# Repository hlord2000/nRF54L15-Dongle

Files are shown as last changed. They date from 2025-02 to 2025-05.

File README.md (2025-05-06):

# Hardware Design with the nRF54L15 is Easy: Making an nRF54L15 Dongle in KiCad

TODO: add flash part, explain firmware bringup on board, get some made 

Everyone knows the nRF52840 dongle! It's an excellent way to prototype with BLE, USB, or Nordic's proprietary protocols ("Enhanced ShockBurst", "Gazelle"). As solid as the dongle is, it's time to add new features and creature comforts to the foundation it gave us. 

First, a short comparison of the nRF54L15 and the nRF52840. Why make the leap to the nRF54L15?
- The nRF54L15 is based on a modern 22nm process, showing a 2x performance increase and half of the power consumption of the nRF52840.
- The nRF54L15 has expanded non-volatile memory as compared to the nRF52840 with 1.5MB onboard (+512KB).
- The nRF54L15 has a peripheral RISC-V core (cool!) which has a lot of interesting uses. It can be used as another core running Zephyr RTOS or as a software defined peripheral with libraries we provide!
- A new 4mbps PHY is available (this supports proprietary protocols only at time of writing).
- New security features are available in the nRF54L15 including a key management unit (KMU), TrustZone, side channel attack detection, and hardware tamper detectors.

How do you perfect perfection? What does an nRF54L15 dongle look like? Any tradeoffs? Here are some things to consider:
- The nRF54L15 does not have a USB interface. We need some sort of chip between the L15 and host device. I propose that we use an nRF52833 to act as a UART bridge and add some extra functionality...
- As seen in the Thingy91 X, it is possible to create a CMSIS-DAP debugger with Zephyr! I'll connect the SWDCLK/SWDIO/RESET pins from the nRF54L15 to the nRF52833.
- Let's add some quality of life items: a STEMMA-QT/Qwiic connector and through holes with castellations.
- It is time for USB-C! We will use a USB-C plug so that it is a true dongle.
- For DFU purposes, we will include a small external flash part connected to the nRF54L15.
- We are not typically power limited with a dongle and do not need a connection to a battery. For more information on power consumption with the nRF54L15, check out the Online Power Profiler here: ##INCLUDE LINK##

We've defined our system, let's make a diagram:

<p align="center">
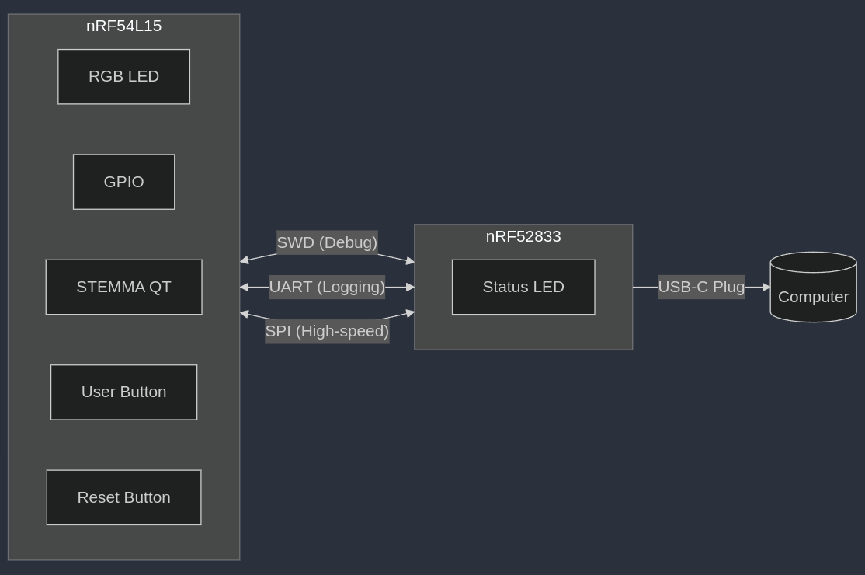
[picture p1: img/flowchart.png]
  
</p>

I personally use KiCad for all hardware design I do. It's quite close to being an outright Altium replacement and the price (free) is hard to pass up. Check out my KiCad library for Nordic parts https://github.com/hlord2000/nordic-lib-kicad if you are also interested!

The nRF52833 can be powered directly from USB, but the nRF54L15 will need a 5V->3.3V regulator. Let's combine this with the USB-C plug and protection IC. 

<p align="center">
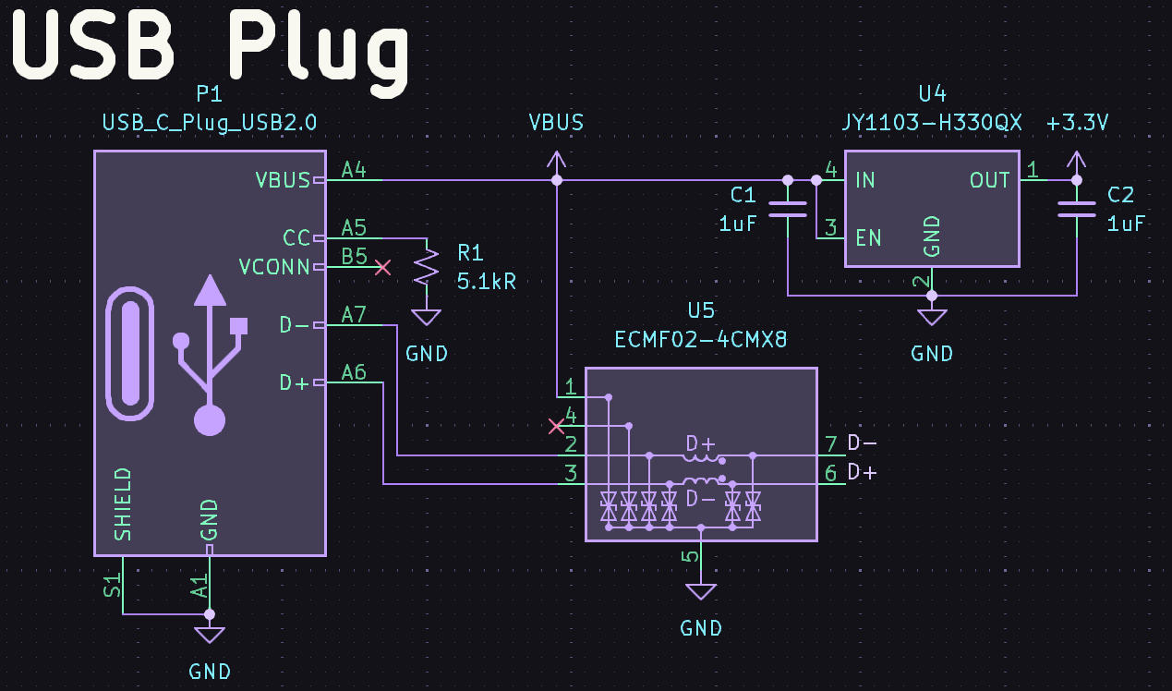
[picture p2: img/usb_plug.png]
  
</p>

Note the use of a 5.1k pull down resistor on the CC pin of the plug. This tells the upstream device, typically a computer, that this is a downstream device that can sink up to 500mA. If you were to need more power, consider using a dedicated USB power delivery (PD) PHY.

Let's move on to the nRF52833 debugger.

<p align="center">
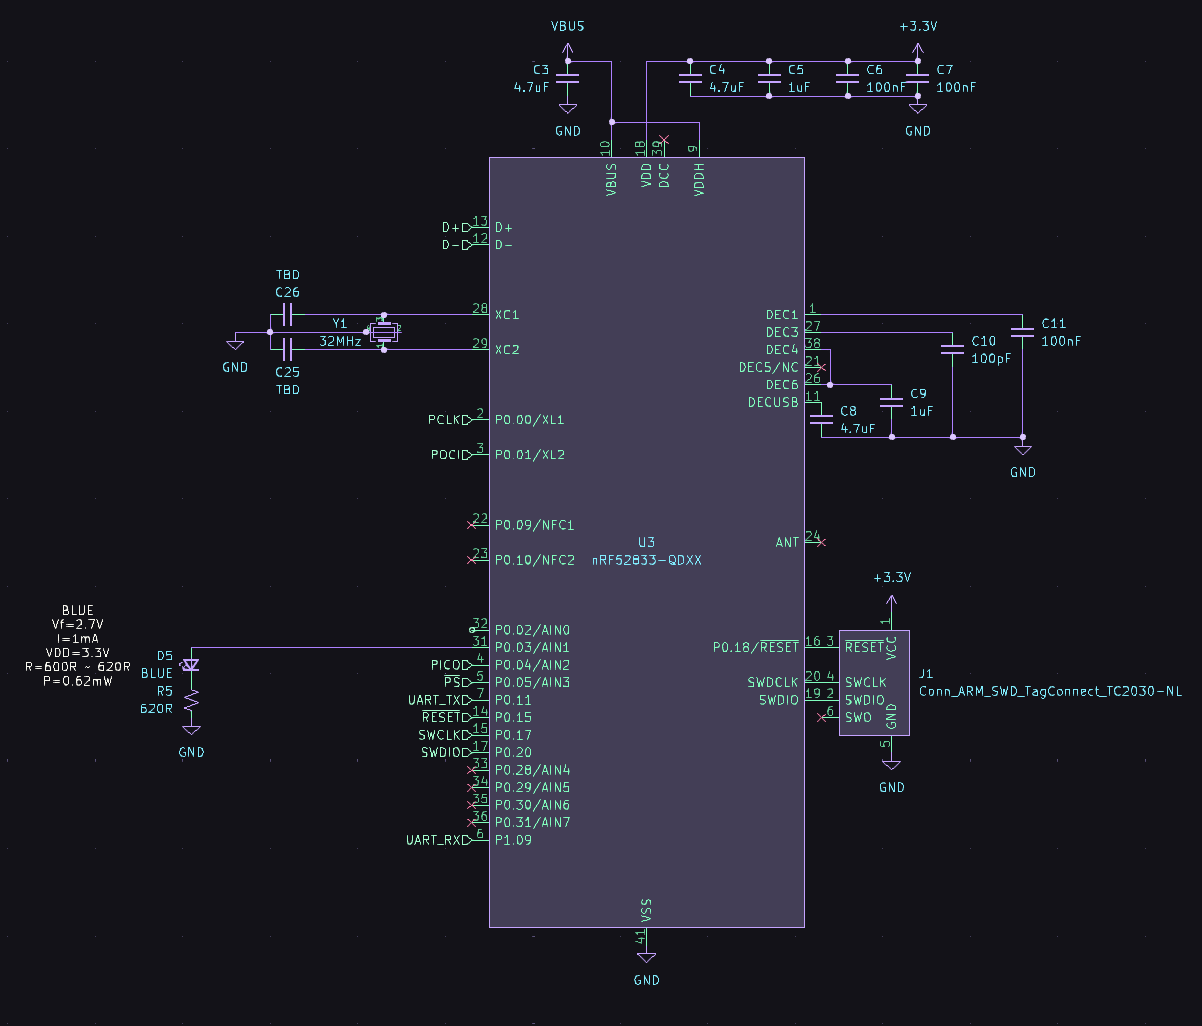
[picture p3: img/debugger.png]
  
</p>

There is no need for an external 32.768KHz crystal oscillator since this design is not power constrained, so we'll use the internal RC oscillator. Any pins can be used for the peripherals on the nRF52833 and the SWD pins are bit-banged anyway, so I have connected them to the most convenient pins for routing to the nRF54L15. One small exception is the pins required to use the 32MHz high-speed SPI interface on the nRF52833 (which requires specific pins for full speed operation).

The nRF52833 debugger can itself be programmed through a Tag Connect TC2030 footprint. This saves a line on the BOM and seems to be quite common in industry. Tag Connect sells a cable that can connect to the debug out port on any Nordic devkit. The onboard debugger will also feature MCUBoot USB DFU if it becomes necessary to update firmware.

Now for the star of the show! I have added the nRF54L15 in QFN package, following the reference design available here (## INCLUDE LINK ##) to ensure correct passive component values. 

<p align="center">
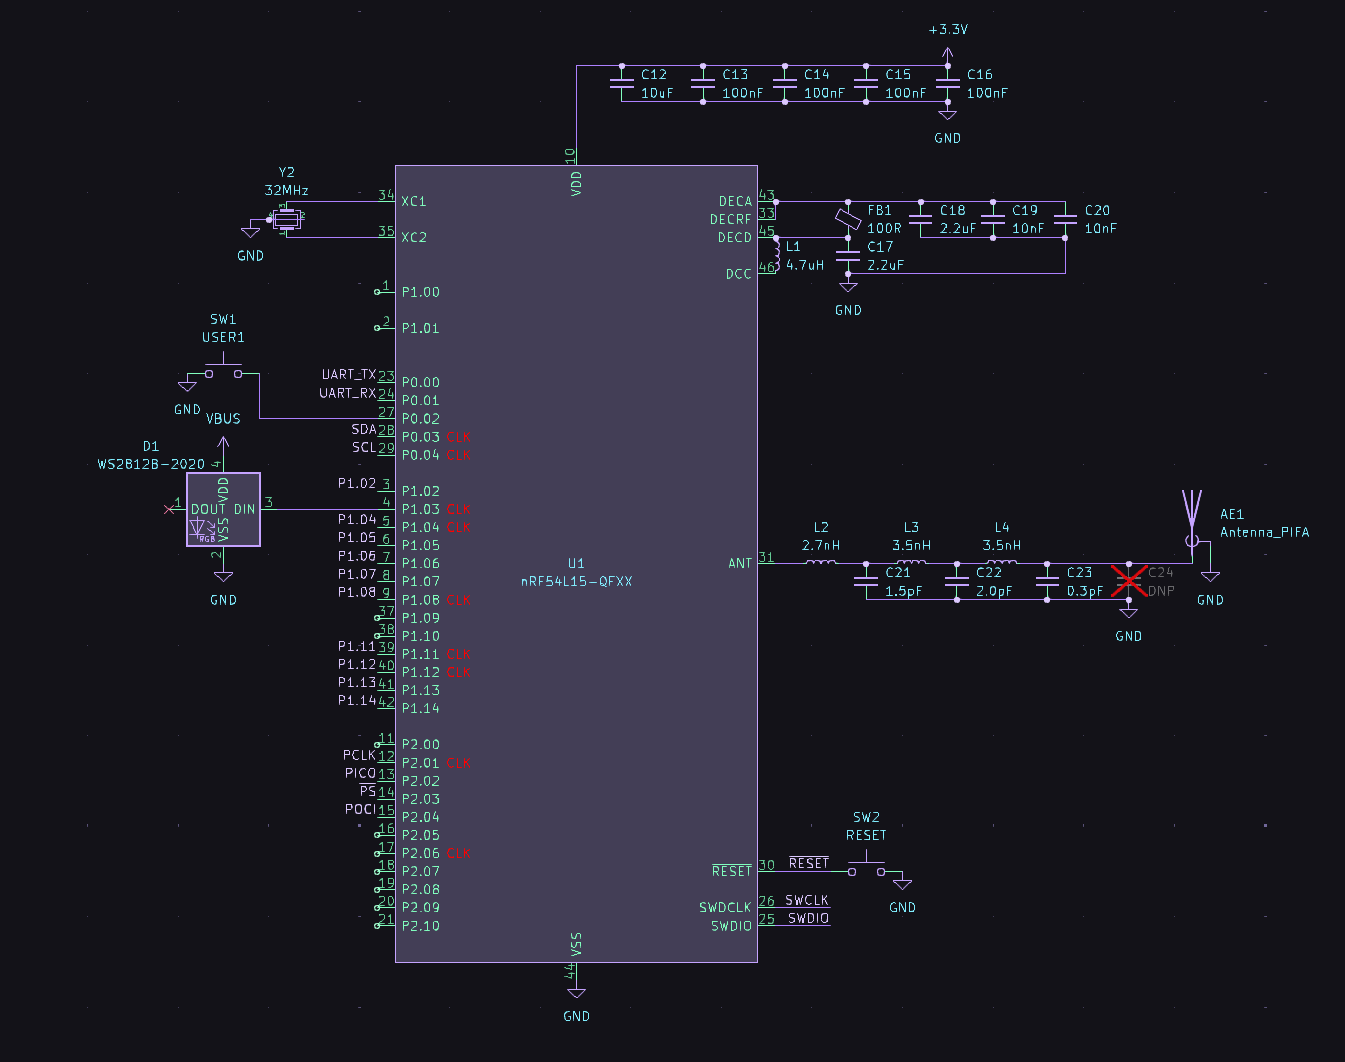
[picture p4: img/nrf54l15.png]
  
</p>

Some notes on the nRF54L15:

- Only GPIO ports 0 and 1 support GPIO interrupts! GPIO port #2 is intended for higher power/faster peripherals and does not have an associated GPIOTE peripheral. Please refer to the product specification for more info on peripheral power domains. Suffice it to say: port 0 is the lowest power port, port 1 is in between, and port 2 uses the most power. Use this when planning what peripheral instances or pins you plan to use.
- With the nRF54L15, certain peripherals require the use of "clock pins." My schematic symbol labels which are clock pins. Refer to the product spec for a complete list of what peripherals require clock pins (SPI SCK requires one among others).
- Some peripherals on GPIO port 2 have assigned pins. (I'm a broken record: refer to the product spec :D)
- The nRF54L15 has internal load capacitors for the high frequency (32MHz) and low frequency (32.768KHz) crystals. Nice to have! This reduces board area and BOM.

For IO, the nRF54L15 has a user button, reset button, addressable LED/NeoPixel, a STEMMA-QT port, and 2.54mm pin header holes with castellated edges.

<p align="center">
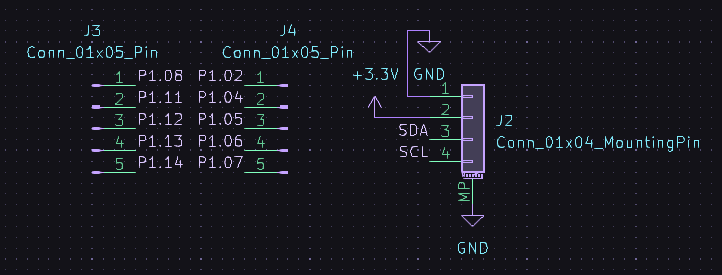
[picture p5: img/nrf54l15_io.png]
  
</p>

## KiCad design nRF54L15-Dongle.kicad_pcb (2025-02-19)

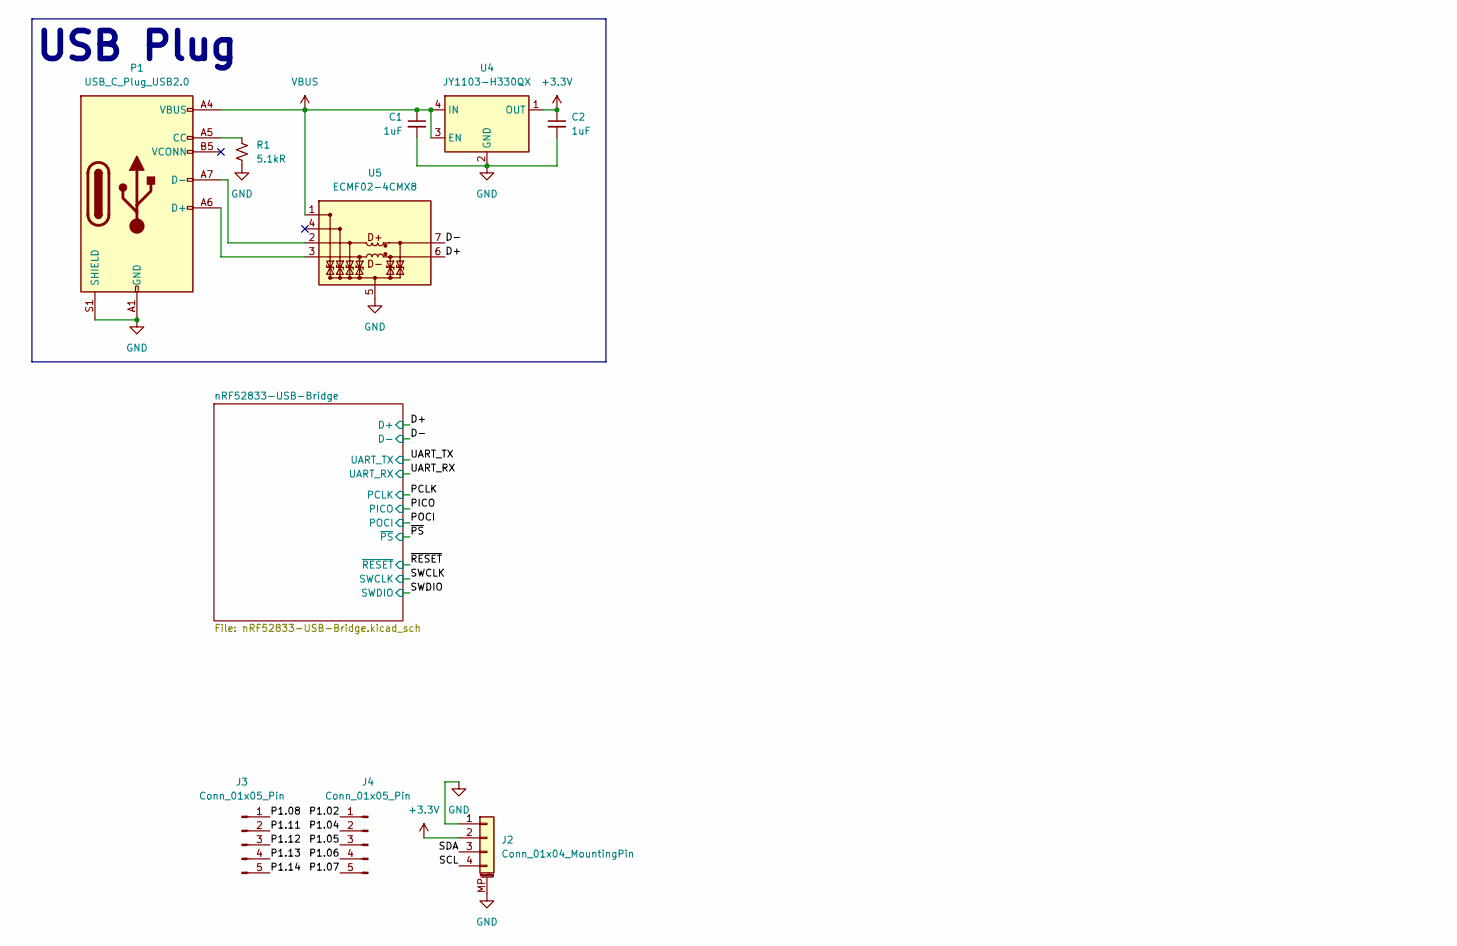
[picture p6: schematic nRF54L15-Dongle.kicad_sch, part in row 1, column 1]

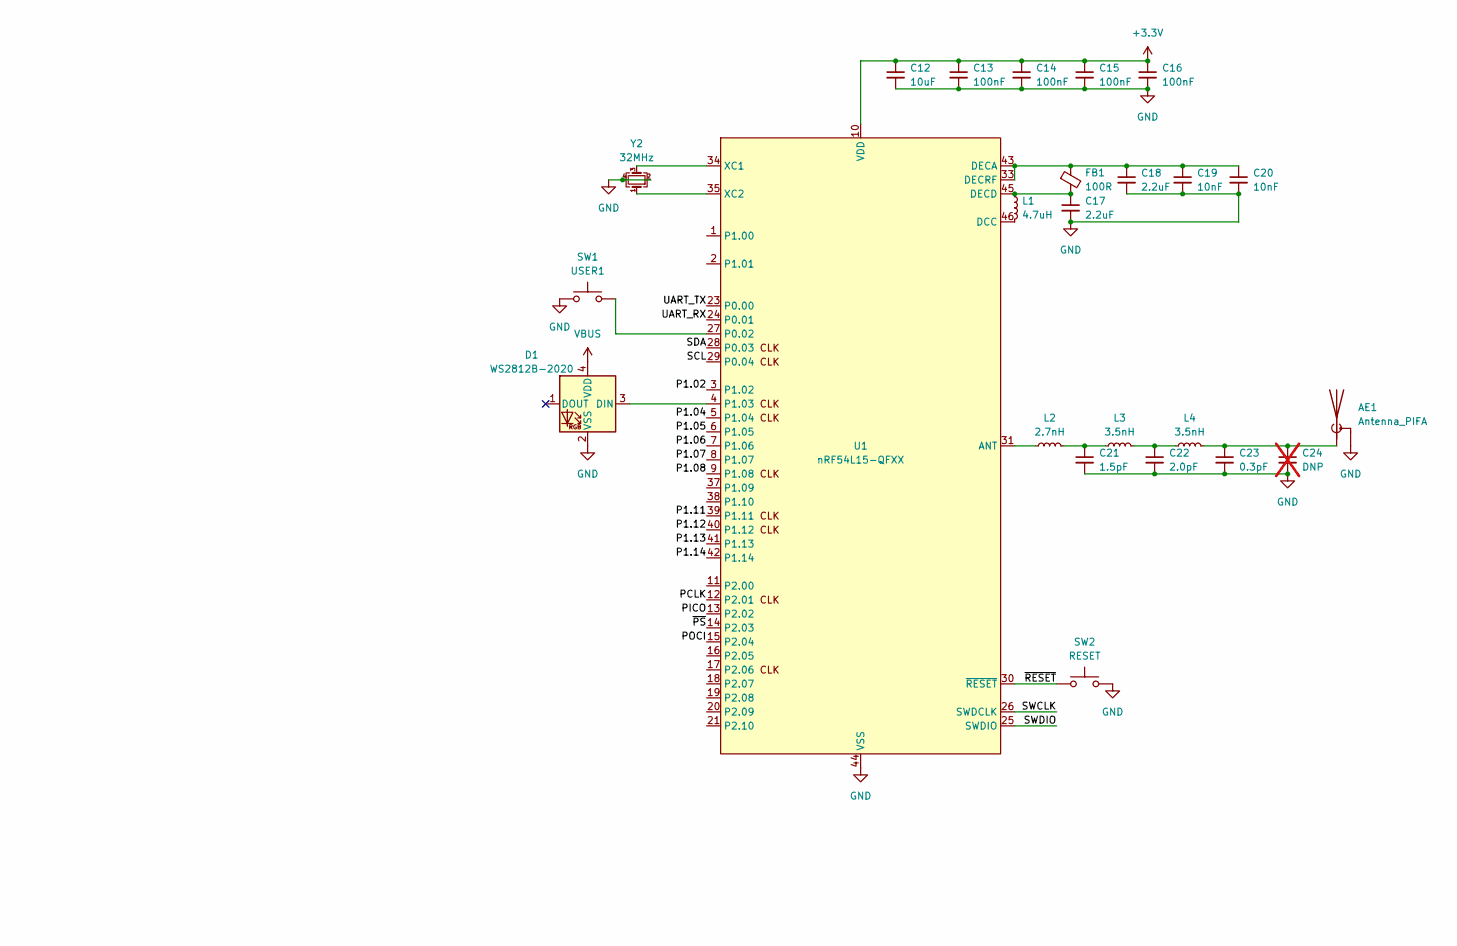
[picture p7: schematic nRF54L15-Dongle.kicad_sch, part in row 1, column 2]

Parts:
AE1: Antenna_PIFA; Texas_SWRA117D_2.4GHz_Left
C1, C2: 1uF; C_0402_1005Metric
C12: 10uF; C_0402_1005Metric
C13, C14, C15, C16: 100nF; C_0402_1005Metric
C17, C18: 2.2uF; C_0402_1005Metric
C19, C20: 10nF; C_0402_1005Metric
C21: 1.5pF; C_0402_1005Metric
C22: 2.0pF; C_0402_1005Metric
C23: 0.3pF; C_0402_1005Metric
C24: DNP; C_0402_1005Metric; not fitted
D1: WS2812B-2020; LED_WS2812B-2020_PLCC4_2.0x2.0mm
FB1: 100R; L_0402_1005Metric
J2: Conn_01x04_MountingPin; JST_SH_SM04B-SRSS-TB_1x04-1MP_P1.00mm_Horizontal
J3, J4: Conn_01x05_Pin; PinHeader_1x05_P2.54mm_Vertical
L1: 4.7uH; L_0402_1005Metric
L2: 2.7nH; L_0402_1005Metric
L3, L4: 3.5nH; L_0402_1005Metric
P1: USB_C_Plug_USB2.0; USB_C_Plug_Molex_105444
R1: 5.1kR; R_0402_1005Metric
SW1: USER1; SW_Push_1P1T_NO_Vertical_Wuerth_434133025816
SW2: RESET; SW_Push_1P1T_NO_Vertical_Wuerth_434133025816
U1: nRF54L15-QFXX; QFN-48-1EP_6x6mm_P0.4mm_EP4.6x4.6mm_ThermalVias
U4: JY1103-H330QX; OnSemi_XDFN4-1EP_1.0x1.0mm_EP0.52x0.52mm; LCSC C3038104
U5: ECMF02-4CMX8; ST_UQFN-8L_1.2x2.5mm_P0.5mm
Y2: 32MHz; Crystal_SMD_2016-4Pin_2.0x1.6mm

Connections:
+3.3V: C2.1, C12.1, C13.1, C14.1, C15.1, C16.1, J2.2, U1.10 (VDD), U1.22 (VDD), U1.36 (VDD), U1.47 (VDD), U1.48 (VDD), U4.1 (OUT); also elsewhere on the board
/D+: U5.6 (D+_out); also elsewhere on the board
/D-: U5.7 (D-_out); also elsewhere on the board
/P1.02: J4.1, U1.3 (P1.02)
/P1.04: J4.2, U1.5 (P1.04)
/P1.05: J4.3, U1.6 (P1.05)
/P1.06: J4.4, U1.7 (P1.06)
/P1.07: J4.5, U1.8 (P1.07)
/P1.08: J3.1, U1.9 (P1.08)
/P1.11: J3.2, U1.39 (P1.11)
/P1.12: J3.3, U1.40 (P1.12)
/P1.13: J3.4, U1.41 (P1.13)
/P1.14: J3.5, U1.42 (P1.14)
/PCLK: U1.12 (P2.01); also elsewhere on the board
/PICO: U1.13 (P2.02); also elsewhere on the board
/POCI: U1.15 (P2.04); also elsewhere on the board
/SCL: J2.4, U1.29 (P0.04)
/SDA: J2.3, U1.28 (P0.03)
/SWCLK: U1.26 (SWDCLK); also elsewhere on the board
/SWDIO: U1.25 (SWDIO); also elsewhere on the board
/UART_RX: U1.24 (P0.01); also elsewhere on the board
/UART_TX: U1.23 (P0.00); also elsewhere on the board
/~PS: U1.14 (P2.03); also elsewhere on the board
/~RESET: SW2.2, U1.30 (~RESET); also elsewhere on the board
GND: AE1.2 (Shield), C1.2, C2.2, C12.2, C13.2, C14.2, C15.2, C16.2, C17.2, C18.2, C19.2, C20.2, C21.2, C22.2, C23.2, C24.2, D1.2 (VSS), J2.1, J2.MP (MountPin), P1.A1 (GND), P1.A12 (GND), P1.B1 (GND), P1.B12 (GND), P1.S1 (SHIELD), R1.2, SW1.1, SW2.1, U1.32 (VSS_PA), U1.44 (VSS), U1.49 (VSS), U4.2 (GND), U4.5 (GND), U5.5 (GND), U5.8 (GND), Y2.2, Y2.4; also elsewhere on the board
unnamed: AE1.1 (A), C23.1, C24.1, L4.2
unnamed: C21.1, L2.2, L3.1
unnamed: C22.1, L3.2, L4.1
unnamed: D1.3 (DIN), U1.4 (P1.03)
unnamed: P1.A5 (CC), R1.1
unnamed: P1.A6 (D+), U5.3 (D+_in)
unnamed: P1.A7 (D-), U5.2 (D-_in)
unnamed: L2.1, U1.31 (ANT)
unnamed: L1.2, U1.46 (DCC)
unnamed: C18.1, C19.1, C20.1, FB1.1, U1.33 (DECRF), U1.43 (DECA)
unnamed: C17.1, FB1.2, L1.1, U1.45 (DECD)
unnamed: SW1.2, U1.27 (P0.02)
unnamed: U1.34 (XC1), Y2.3
unnamed: U1.35 (XC2), Y2.1
VBUS: C1.1, D1.4 (VDD), P1.A4 (VBUS), P1.A9 (VBUS), P1.B4 (VBUS), P1.B9 (VBUS), U4.3 (EN), U4.4 (IN), U5.1 (VBUS); also elsewhere on the board

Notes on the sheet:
USB Plug

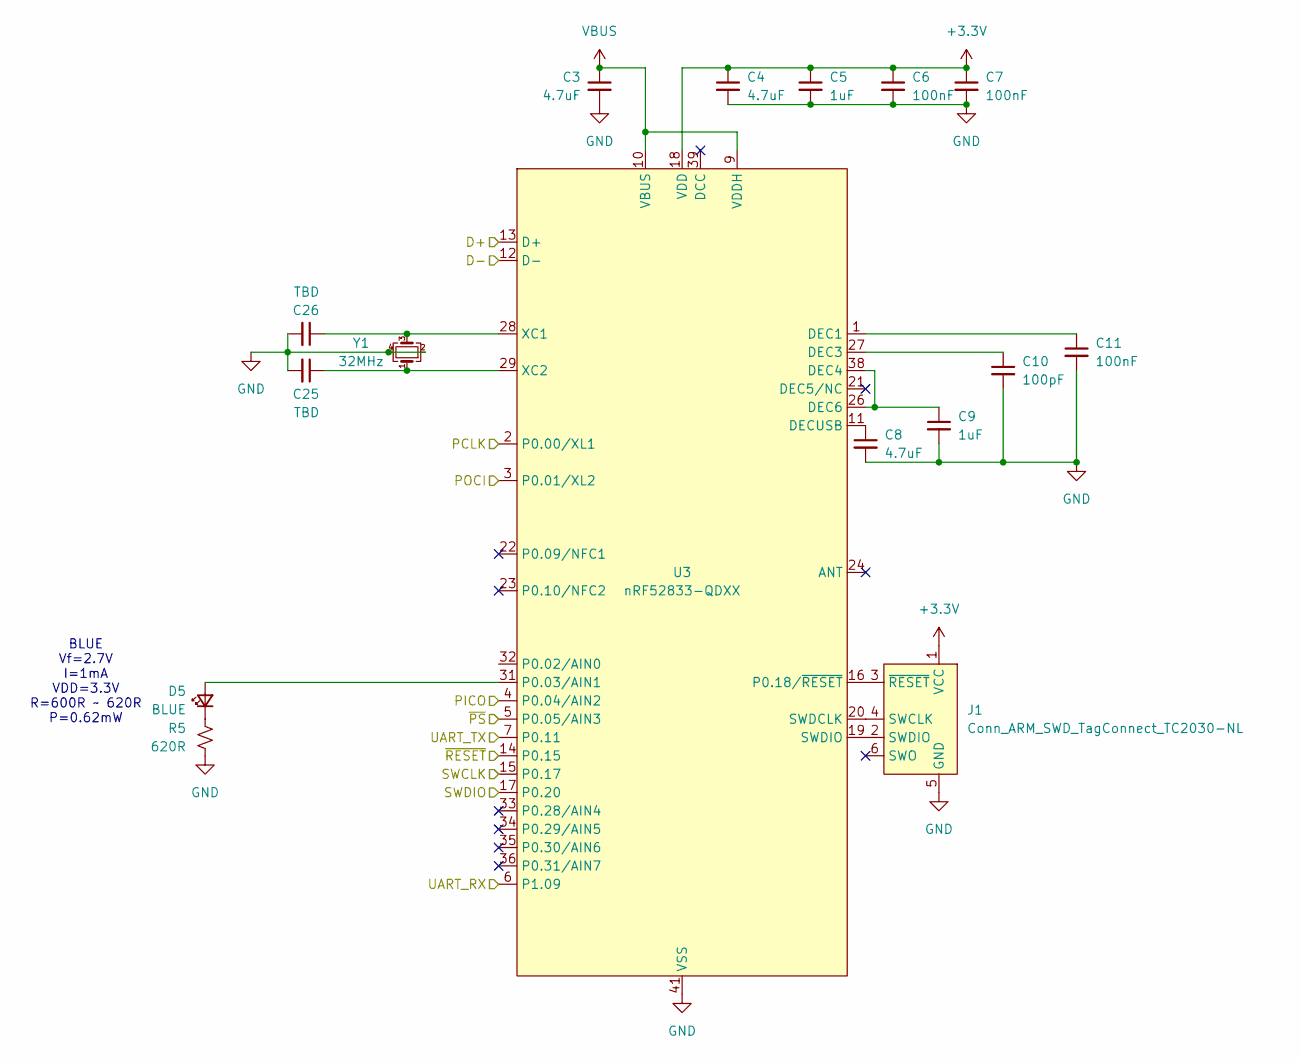
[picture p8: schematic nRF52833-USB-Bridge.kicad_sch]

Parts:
C3, C4, C8: 4.7uF; C_0402_1005Metric
C5, C9: 1uF; C_0402_1005Metric
C6, C7, C11: 100nF; C_0402_1005Metric
C10: 100pF; C_0402_1005Metric
C25, C26: TBD; C_0402_1005Metric
D5: BLUE; LED_0603_1608Metric; LCSC C7496819
J1: Conn_ARM_SWD_TagConnect_TC2030-NL; Tag-Connect_TC2030-IDC-NL_2x03_P1.27mm_Vertical
R5: 620R; R_0402_1005Metric
U3: nRF52833-QDXX; QFN-40-1EP_5x5mm_P0.4mm_EP3.6x3.6mm_ThermalVias
Y1: 32MHz; Crystal_SMD_2016-4Pin_2.0x1.6mm

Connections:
+3.3V: C4.1, C5.1, C6.1, C7.1, J1.1 (VCC), U3.8 (VDD), U3.18 (VDD), U3.30 (VDD), U3.40 (VDD); also elsewhere on the board
/D+: U3.13 (D+); also elsewhere on the board
/D-: U3.12 (D-); also elsewhere on the board
/PCLK: U3.2 (P0.00/XL1); also elsewhere on the board
/PICO: U3.4 (P0.04/AIN2); also elsewhere on the board
/POCI: U3.3 (P0.01/XL2); also elsewhere on the board
/SWCLK: U3.15 (P0.17); also elsewhere on the board
/SWDIO: U3.17 (P0.20); also elsewhere on the board
/UART_RX: U3.6 (P1.09); also elsewhere on the board
/UART_TX: U3.7 (P0.11); also elsewhere on the board
/~PS: U3.5 (P0.05/AIN3); also elsewhere on the board
/~RESET: U3.14 (P0.15); also elsewhere on the board
GND: C3.2, C4.2, C5.2, C6.2, C7.2, C8.2, C9.2, C10.2, C11.2, C25.2, C26.2, J1.5 (GND), R5.2, U3.25 (VSS_PA), U3.37 (VSS), U3.41 (VSS), Y1.2, Y1.4; also elsewhere on the board
unnamed: D5.2 (A), U3.31 (P0.03/AIN1)
unnamed: D5.1 (K), R5.1
unnamed: J1.4 (SWCLK), U3.20 (SWDCLK)
unnamed: J1.2 (SWDIO), U3.19 (SWDIO)
unnamed: J1.3 (~RESET), U3.16 (P0.18/~RESET)
unnamed: C11.1, U3.1 (DEC1)
unnamed: C10.1, U3.27 (DEC3)
unnamed: C9.1, U3.26 (DEC6), U3.38 (DEC4)
unnamed: C8.1, U3.11 (DECUSB)
unnamed: C26.1, U3.28 (XC1), Y1.3
unnamed: C25.1, U3.29 (XC2), Y1.1
VBUS: C3.1, U3.9 (VDDH), U3.10 (VBUS); also elsewhere on the board

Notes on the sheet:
BLUE Vf=2.7V I=1mA VDD=3.3V R=600R ~ 620R P=0.62mW

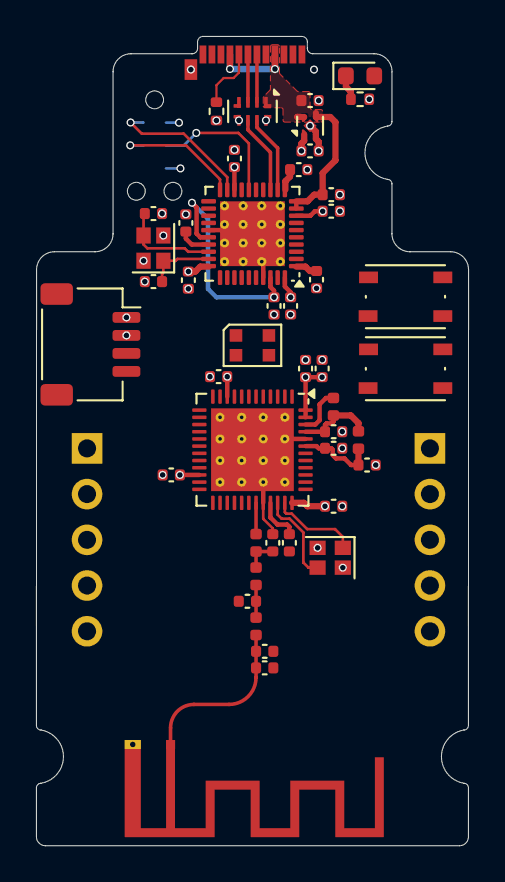
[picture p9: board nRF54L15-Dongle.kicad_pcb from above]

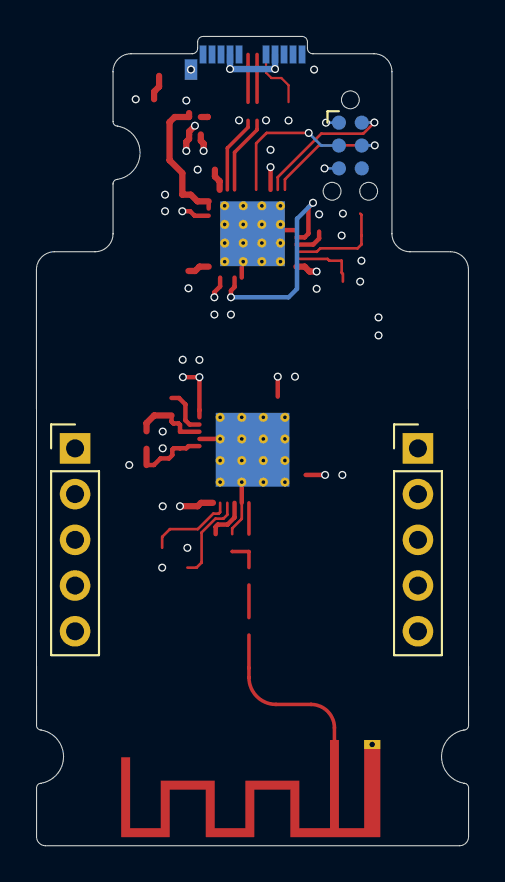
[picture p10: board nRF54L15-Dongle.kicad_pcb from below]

Board: 4 copper layers, 24.0 x 45.0 mm, 49 parts (3 on the bottom side), 49 nets.
